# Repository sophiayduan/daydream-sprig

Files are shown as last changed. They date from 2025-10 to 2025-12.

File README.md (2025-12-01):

# Daydream-Sprig

#### The Daydream-Sprig is a version of the [Sprig](https://github.com/hackclub/sprig) using the bare RP2040 chip and in a vertical handheld formfactor.





I'll be setting it up the same as the Sprig. flashing Spade OS (Sprigs custom operating system)

### Features 
- All pre-exsiting sprig stuff (Rp2040, ST7735 1.8" Display, powered via 2xaaa, etc)
- 6x6mm push buttons
- Vertical handheld form factor
- 4 additional GPIOS
- Cool silkscreen art made by Erin + some stolen from the og sprig

(unlike the original sprig, this board doesn't include a speaker due to its cost)

This project was made as a lanyard for [Daydream Ottawa](https://daydream.hackclub.com/ottawa) organizers (to display their names and other cool stuff) but, I didn't end up finishing it in time oops.

## Acknowledgements
*the sprig.*

jlcpcb 

Thanks JLCPCB for sponsoring DD Ottawa and hence this project.

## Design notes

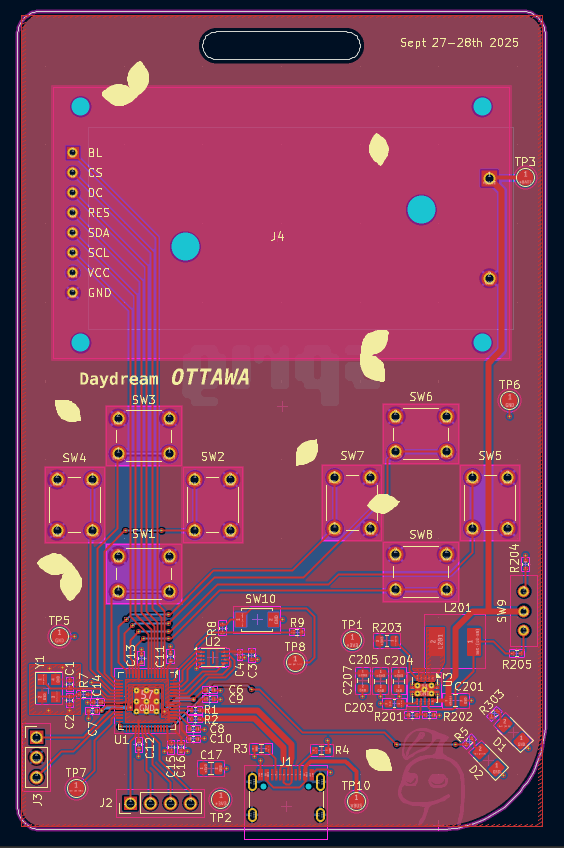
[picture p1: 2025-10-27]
images/pcb_front.png

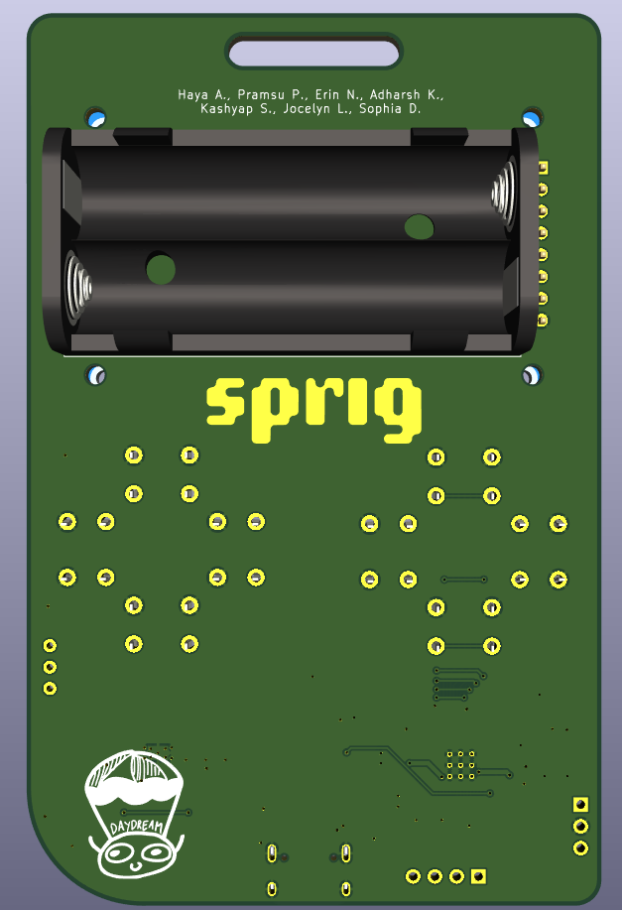
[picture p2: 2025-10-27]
images/3d_back.png

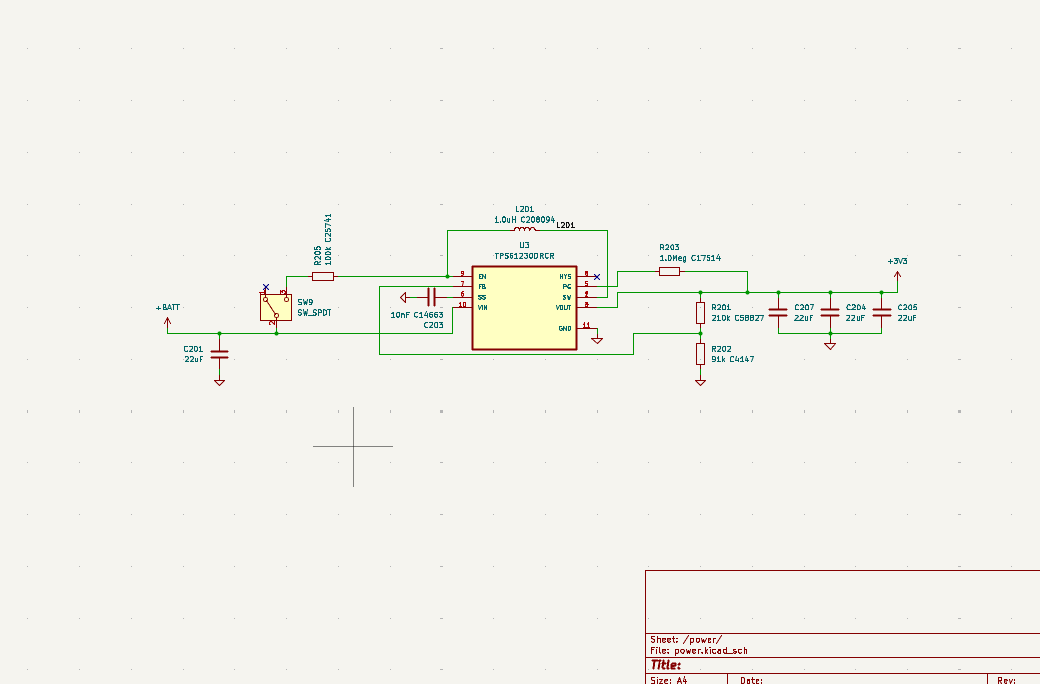
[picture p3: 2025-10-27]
images/sch_power.png

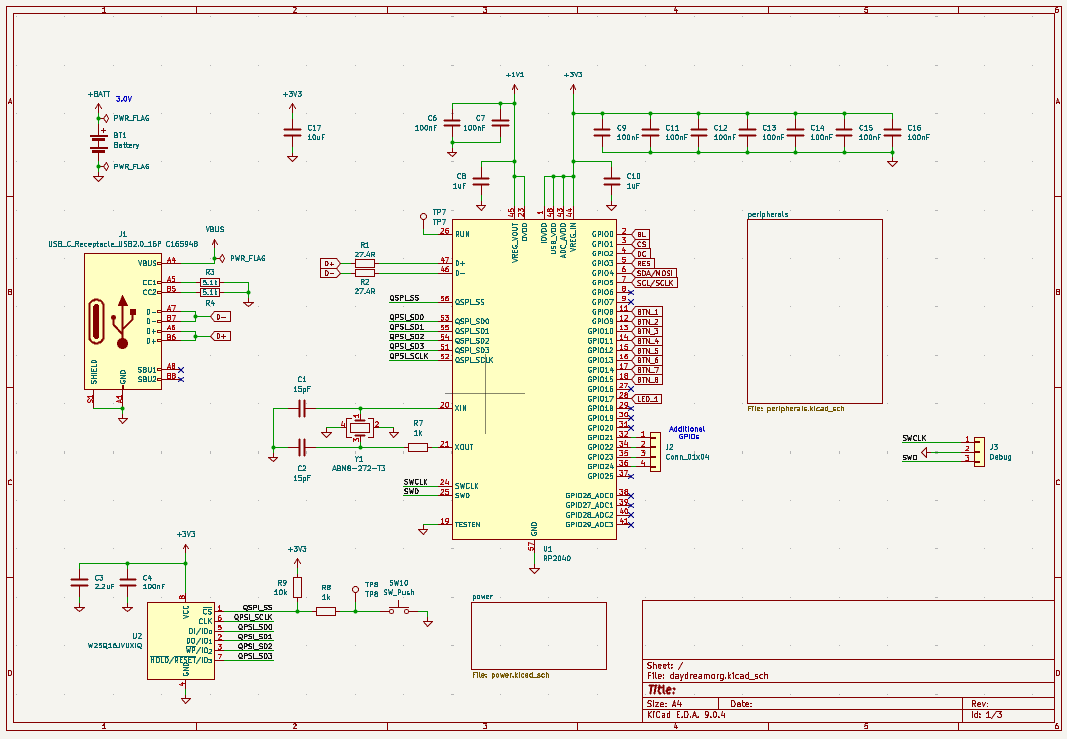
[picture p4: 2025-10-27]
images/sch_main.png

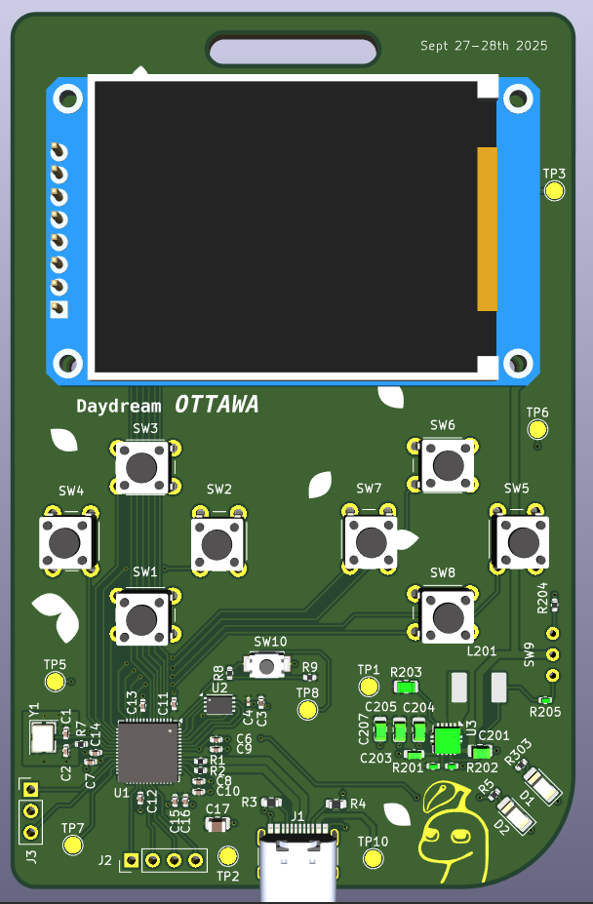
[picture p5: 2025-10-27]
images/3d_front.png

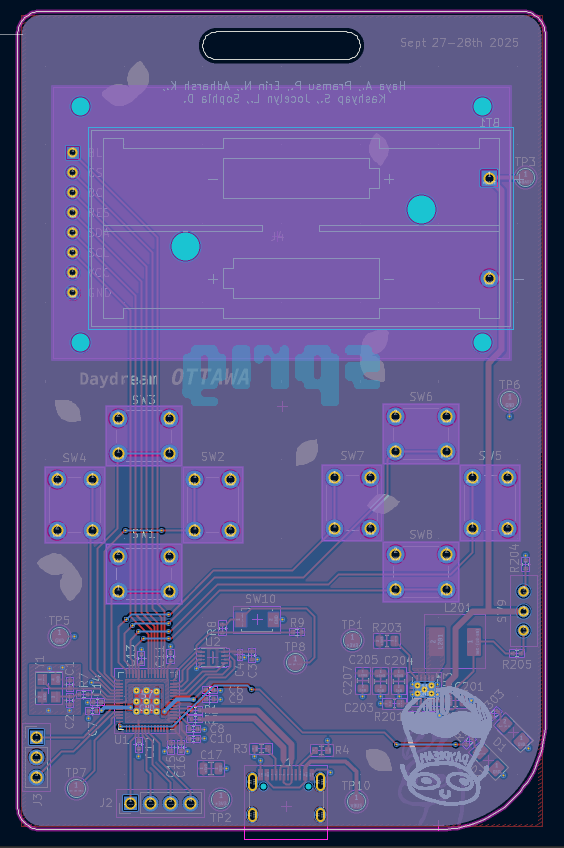
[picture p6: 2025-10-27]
images/pcb_back.png

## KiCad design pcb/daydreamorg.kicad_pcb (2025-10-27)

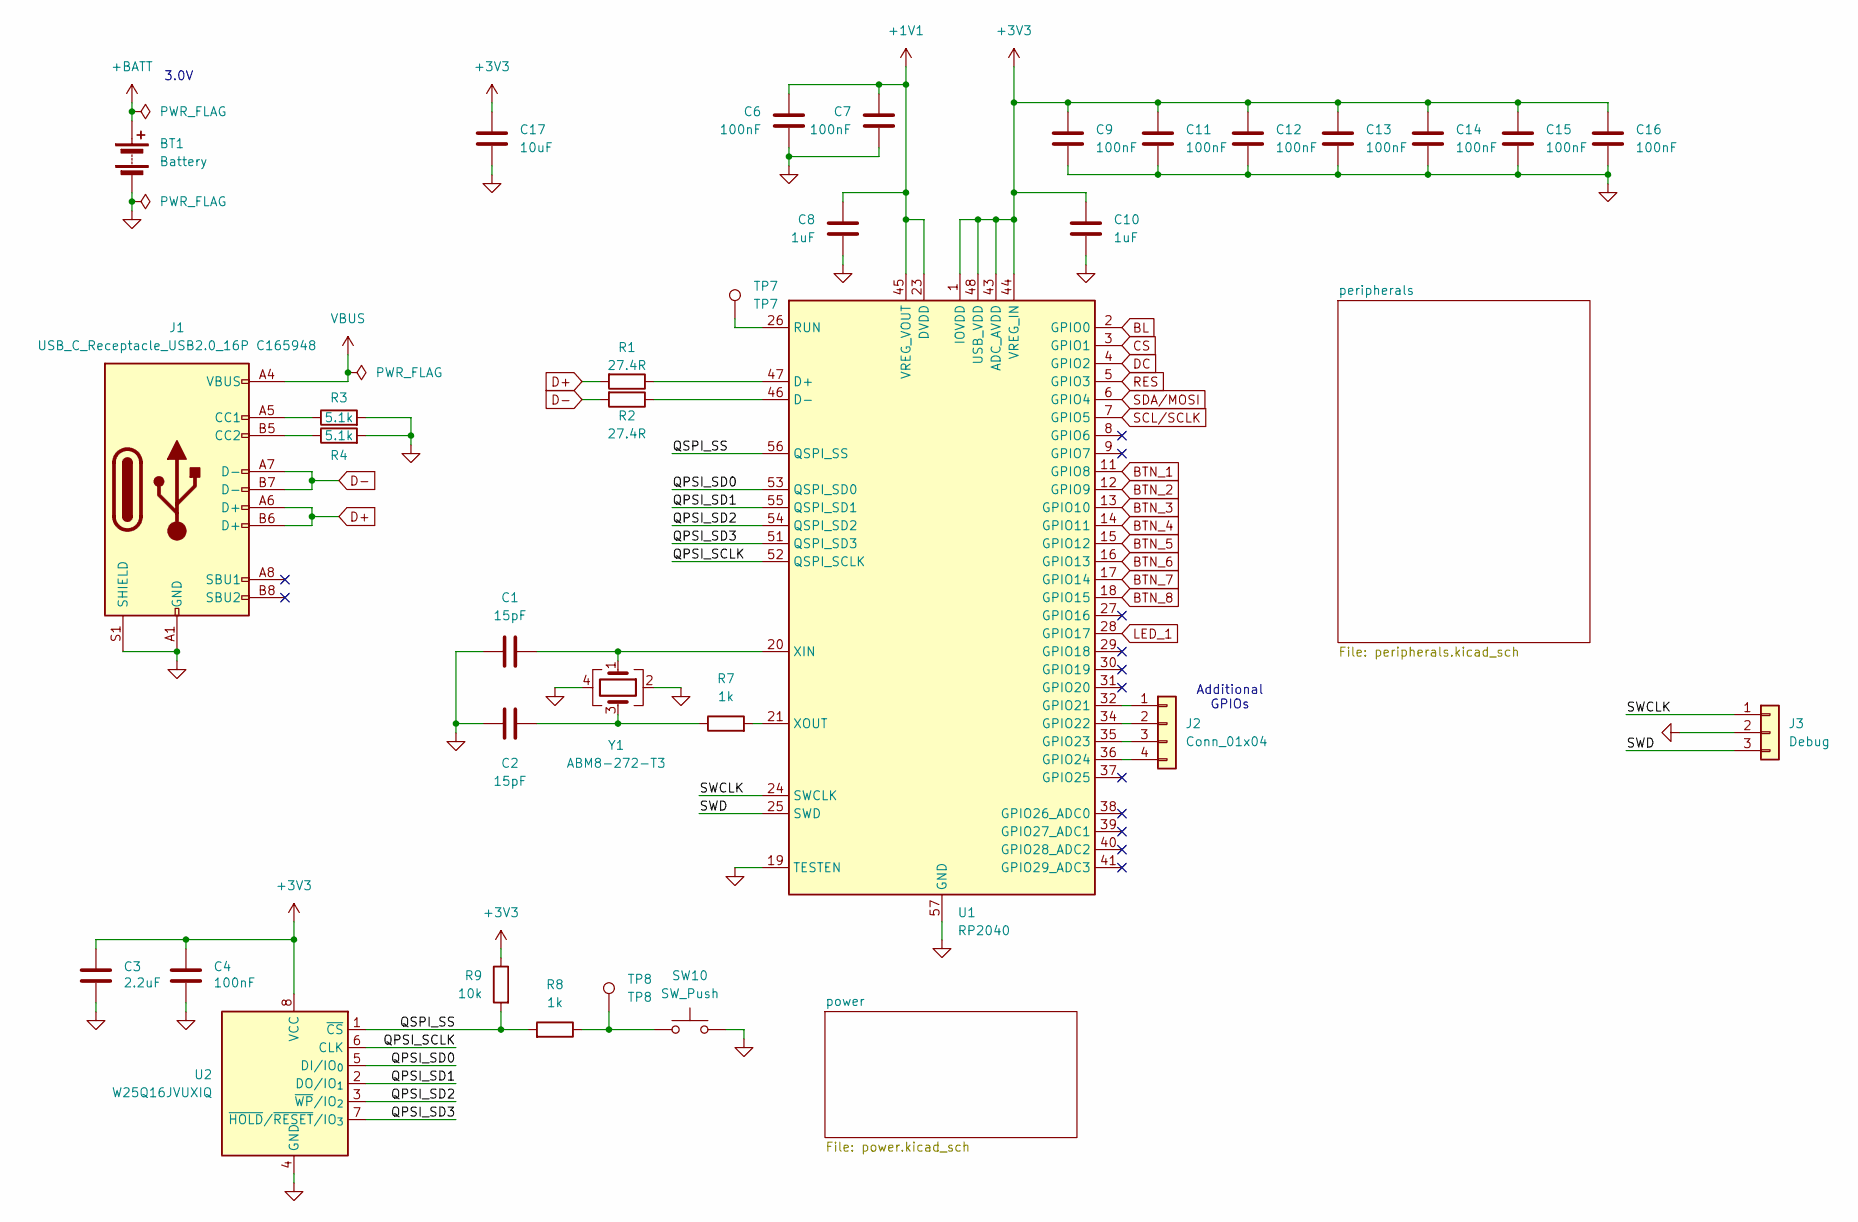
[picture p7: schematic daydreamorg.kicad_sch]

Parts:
BT1: Battery; BatteryHolder_Keystone_2468_2xAAA; LCSC C254917
C1, C2: 15pF; C_0402_1005Metric; LCSC C1548
C3: 2.2uF; C_0402_1005Metric; LCSC C541409
C4: 100nF; C_0603_1608Metric; LCSC C1525
C6, C7, C9, C11, C12, C13, C14, C15, C16: 100nF; C_0402_1005Metric; LCSC C1525
C8, C10: 1uF; C_0402_1005Metric; LCSC C52923
C17: 10uF; C_0805_2012Metric
J1: USB_C_Receptacle_USB2.0_16P C165948; USB_C_Receptacle_HRO_TYPE-C-31-M-12; LCSC C165948
J2: Conn_01x04; PinHeader_1x04_P2.54mm_Vertical
J3: Debug; PinHeader_1x03_P2.54mm_Vertical
R1, R2: 27.4R; R_0402_1005Metric; LCSC C25100
R3, R4: 5.1k; R_0603_1608Metric; LCSC C23186
R7, R8: 1k; R_0402_1005Metric; LCSC C11702
R9: 10k; R_0402_1005Metric
SW10: SW_Push; SW_TS-1088-AR02016; LCSC C720477
TP7: TP7; TestPoint_Pad_D2.0mm
TP8: TP8; TestPoint_Pad_D2.0mm
U1: RP2040; QFN-56-1EP_7x7mm_P0.4mm_EP3.2x3.2mm; LCSC C2040
U2: W25Q16JVUXIQ; SOIC-8_5.3x5.3mm_P1.27mm; LCSC C2843335
Y1: ABM8-272-T3; Crystal_SMD_3225-4Pin_3.2x2.5mm; LCSC C20625731

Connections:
+1V1: C6.1, C7.1, C8.1, U1.23 (DVDD), U1.45 (VREG_VOUT), U1.50 (DVDD)
+3V3: C3.1, C4.1, C9.1, C10.1, C11.1, C12.1, C13.1, C14.1, C15.1, C16.1, C17.1, R9.1, U1.1 (IOVDD), U1.10 (IOVDD), U1.22 (IOVDD), U1.33 (IOVDD), U1.42 (IOVDD), U1.43 (ADC_AVDD), U1.44 (VREG_IN), U1.48 (USB_VDD), U1.49 (IOVDD), U2.8 (VCC); also elsewhere on the board
+BATT: BT1.1 (+); also elsewhere on the board
/QPSI_SCLK: U1.52 (QSPI_SCLK), U2.6 (CLK)
/QPSI_SD0: U1.53 (QSPI_SD0), U2.5 (DI/IO_{0})
/QPSI_SD1: U1.55 (QSPI_SD1), U2.2 (DO/IO_{1})
/QPSI_SD2: U1.54 (QSPI_SD2), U2.3 (~WP/IO_{2})
/QPSI_SD3: U1.51 (QSPI_SD3), U2.7 (~HOLD/~RESET/IO_{3})
/QSPI_SS: R8.2, R9.2, U1.56 (QSPI_SS), U2.1 (~CS)
/SWCLK: J3.1, U1.24 (SWCLK)
/SWD: J3.3, U1.25 (SWD)
BL: U1.2 (GPIO0); also elsewhere on the board
BTN_1: U1.11 (GPIO8); also elsewhere on the board
BTN_2: U1.12 (GPIO9); also elsewhere on the board
BTN_3: U1.13 (GPIO10); also elsewhere on the board
BTN_4: U1.14 (GPIO11); also elsewhere on the board
BTN_5: U1.15 (GPIO12); also elsewhere on the board
BTN_6: U1.16 (GPIO13); also elsewhere on the board
BTN_7: U1.17 (GPIO14); also elsewhere on the board
BTN_8: U1.18 (GPIO15); also elsewhere on the board
CS: U1.3 (GPIO1); also elsewhere on the board
D+: J1.A6 (D+), J1.B6 (D+), R1.2
D-: J1.A7 (D-), J1.B7 (D-), R2.2
DC: U1.4 (GPIO2); also elsewhere on the board
GND: BT1.2 (-), C1.1, C2.1, C3.2, C4.2, C6.2, C7.2, C8.2, C9.2, C10.2, C11.2, C12.2, C13.2, C14.2, C15.2, C16.2, C17.2, J1.A1 (GND), J1.A12 (GND), J1.B1 (GND), J1.B12 (GND), J1.S1 (SHIELD), J3.2, R3.2, R4.2, SW10.2, U1.19 (TESTEN), U1.57 (GND), U2.4 (GND), Y1.2, Y1.4; also elsewhere on the board
LED_1: U1.28 (GPIO17); also elsewhere on the board
unnamed: C2.2, R7.1, Y1.3
unnamed: J1.A5 (CC1), R3.1
unnamed: J1.B5 (CC2), R4.1
unnamed: J2.1, U1.32 (GPIO21)
unnamed: J2.2, U1.34 (GPIO22)
unnamed: J2.3, U1.35 (GPIO23)
unnamed: J2.4, U1.36 (GPIO24)
unnamed: R8.1, SW10.1, TP8.1
unnamed: R1.1, U1.47 (D+)
unnamed: R2.1, U1.46 (D-)
unnamed: TP7.1, U1.26 (RUN)
unnamed: C1.2, U1.20 (XIN), Y1.1
unnamed: R7.2, U1.21 (XOUT)
RES: U1.5 (GPIO3); also elsewhere on the board
SCL/SCLK: U1.7 (GPIO5); also elsewhere on the board
SDA/MOSI: U1.6 (GPIO4); also elsewhere on the board
VBUS: J1.A4 (VBUS), J1.A9 (VBUS), J1.B4 (VBUS), J1.B9 (VBUS); also elsewhere on the board

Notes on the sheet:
Additional GPIOs
3.0V

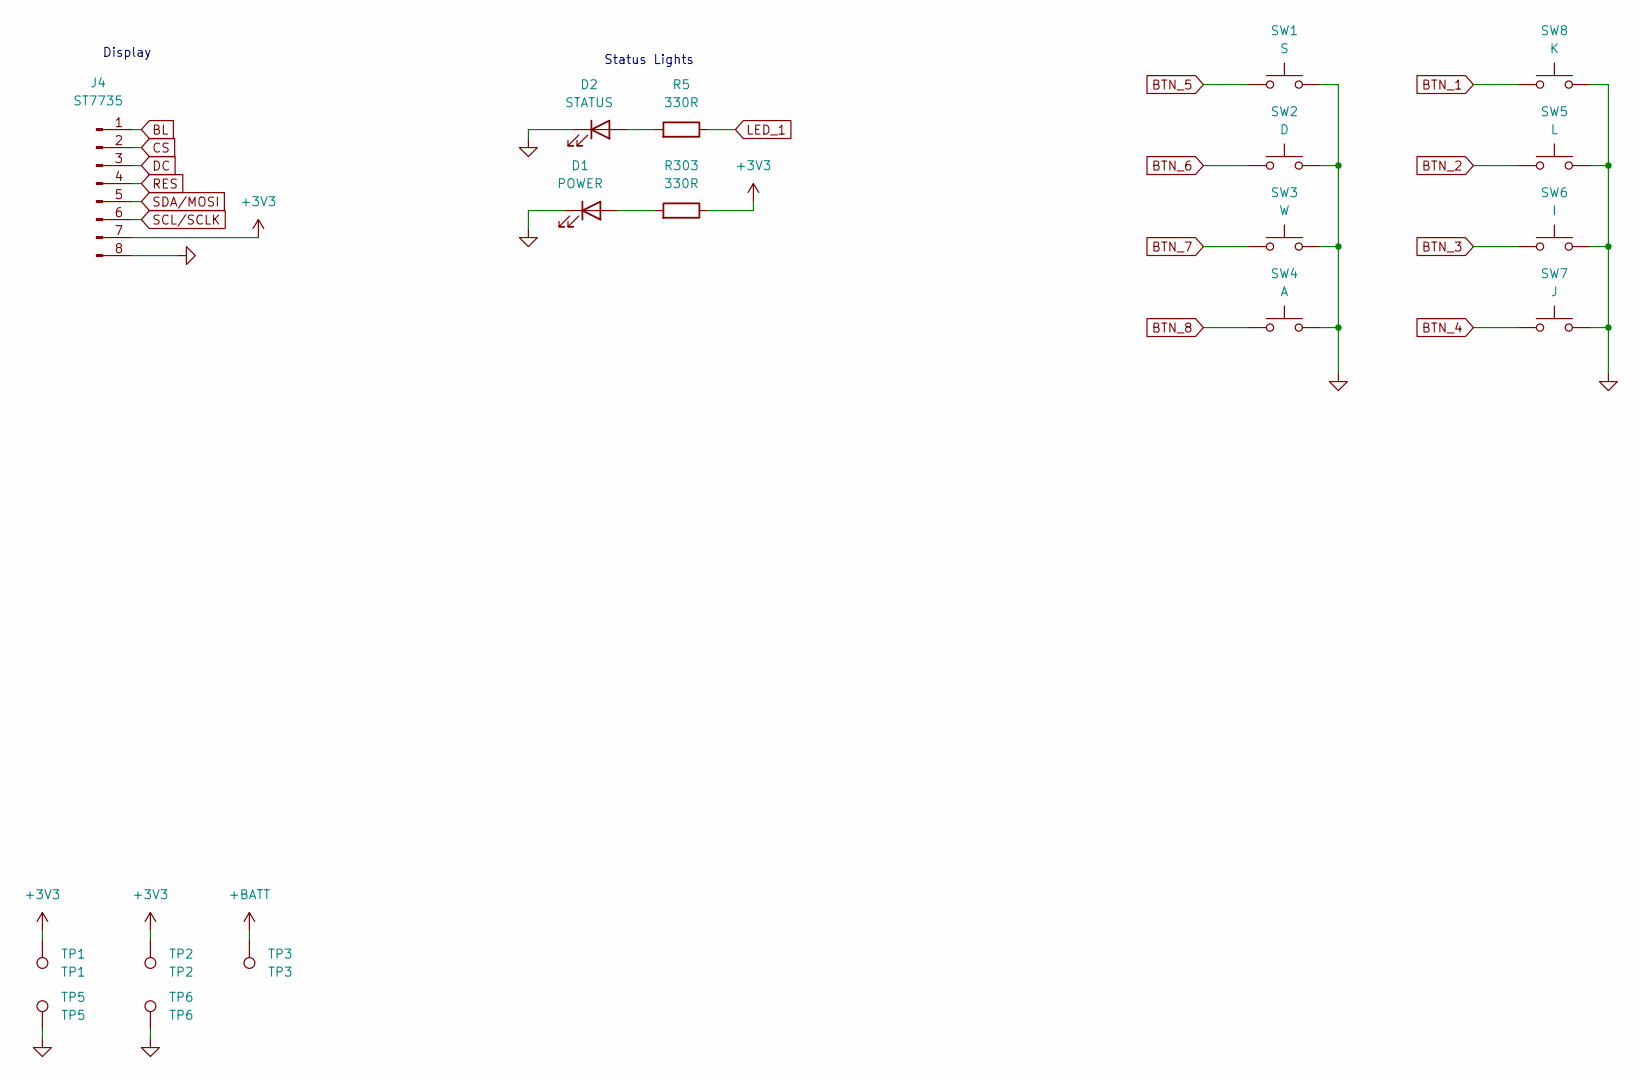
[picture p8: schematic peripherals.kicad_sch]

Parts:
D1: POWER; LED_1206_3216Metric_Pad1.42x1.75mm_HandSolder; LCSC C14641
D2: STATUS; LED_1206_3216Metric_Pad1.42x1.75mm_HandSolder; LCSC C49018
J4: ST7735; st7735
R5, R303: 330R; R_0402_1005Metric; LCSC C25104
SW1: S; SW_PUSH_6mm; LCSC C83205
SW2: D; SW_PUSH_6mm; LCSC C83205
SW3: W; SW_PUSH_6mm; LCSC C83205
SW4: A; SW_PUSH_6mm; LCSC C83205
SW5: L; SW_PUSH_6mm; LCSC C83205
SW6: I; SW_PUSH_6mm; LCSC C83205
SW7: J; SW_PUSH_6mm; LCSC C83205
SW8: K; SW_PUSH_6mm; LCSC C83205
TP1: TP1; TestPoint_Pad_D2.0mm
TP2: TP2; TestPoint_Pad_D2.0mm
TP3: TP3; TestPoint_Pad_D2.0mm
TP5: TP5; TestPoint_Pad_D2.0mm
TP6: TP6; TestPoint_Pad_D2.0mm

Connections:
+3V3: J4.7, R303.1, TP1.1, TP2.1; also elsewhere on the board
+BATT: TP3.1; also elsewhere on the board
BL: J4.1; also elsewhere on the board
BTN_1: SW8.1; also elsewhere on the board
BTN_2: SW5.1; also elsewhere on the board
BTN_3: SW6.1; also elsewhere on the board
BTN_4: SW7.1; also elsewhere on the board
BTN_5: SW1.1; also elsewhere on the board
BTN_6: SW2.1; also elsewhere on the board
BTN_7: SW3.1; also elsewhere on the board
BTN_8: SW4.1; also elsewhere on the board
CS: J4.2; also elsewhere on the board
DC: J4.3; also elsewhere on the board
GND: D1.1 (K), D2.1 (K), J4.8, SW1.2, SW2.2, SW3.2, SW4.2, SW5.2, SW6.2, SW7.2, SW8.2, TP5.1, TP6.1; also elsewhere on the board
LED_1: R5.1; also elsewhere on the board
unnamed: D1.2 (A), R303.2
unnamed: D2.2 (A), R5.2
RES: J4.4; also elsewhere on the board
SCL/SCLK: J4.6; also elsewhere on the board
SDA/MOSI: J4.5; also elsewhere on the board

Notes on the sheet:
Display
Status Lights

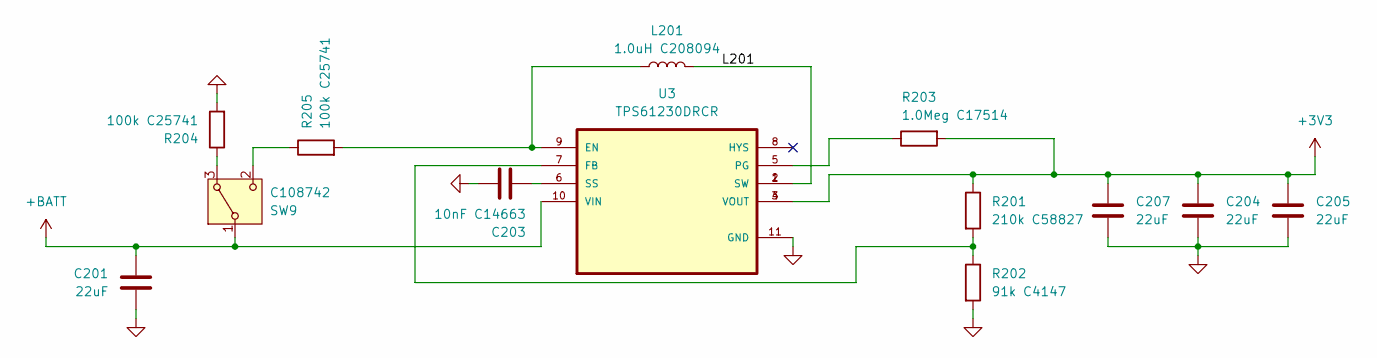
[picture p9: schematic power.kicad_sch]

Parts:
C201: 22uF; C_0805_2012Metric; LCSC C77071
C203: 10nF C14663; C_0603_1608Metric; LCSC C14663
C204, C205, C207: 22uF; C_0805_2012Metric; LCSC C92811
L201: 1.0uH C208094; Untitled_1; LCSC C208094
R201: 210k C58827; R_0402_1005Metric; LCSC C58827
R202: 91k C4147; R_0402_1005Metric; LCSC C4147
R203: 1.0Meg C17514; R_0805_2012Metric; LCSC C17514
R204, R205: 100k C25741; R_0402_1005Metric; LCSC C25741
SW9: C108742; slide switch; LCSC C108742
U3: TPS61230DRCR; TPS123

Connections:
+3V3: C204.1, C205.1, C207.1, R201.1, R203.2, U3.3 (VOUT), U3.4 (VOUT); also elsewhere on the board
+BATT: C201.1, SW9.1 (B), U3.10 (VIN); also elsewhere on the board
/power/L201: L201.2, U3.1 (SW), U3.2 (SW)
GND: C201.2, C203.2, C204.2, C205.2, C207.2, R202.2, R204.2, U3.11 (GND); also elsewhere on the board
unnamed: R204.1, SW9.3 (A)
unnamed: R205.1, SW9.2 (C)
unnamed: L201.1, R205.2, U3.9 (EN)
unnamed: R201.2, R202.1, U3.7 (FB)
unnamed: R203.1, U3.5 (PG)
unnamed: C203.1, U3.6 (SS)

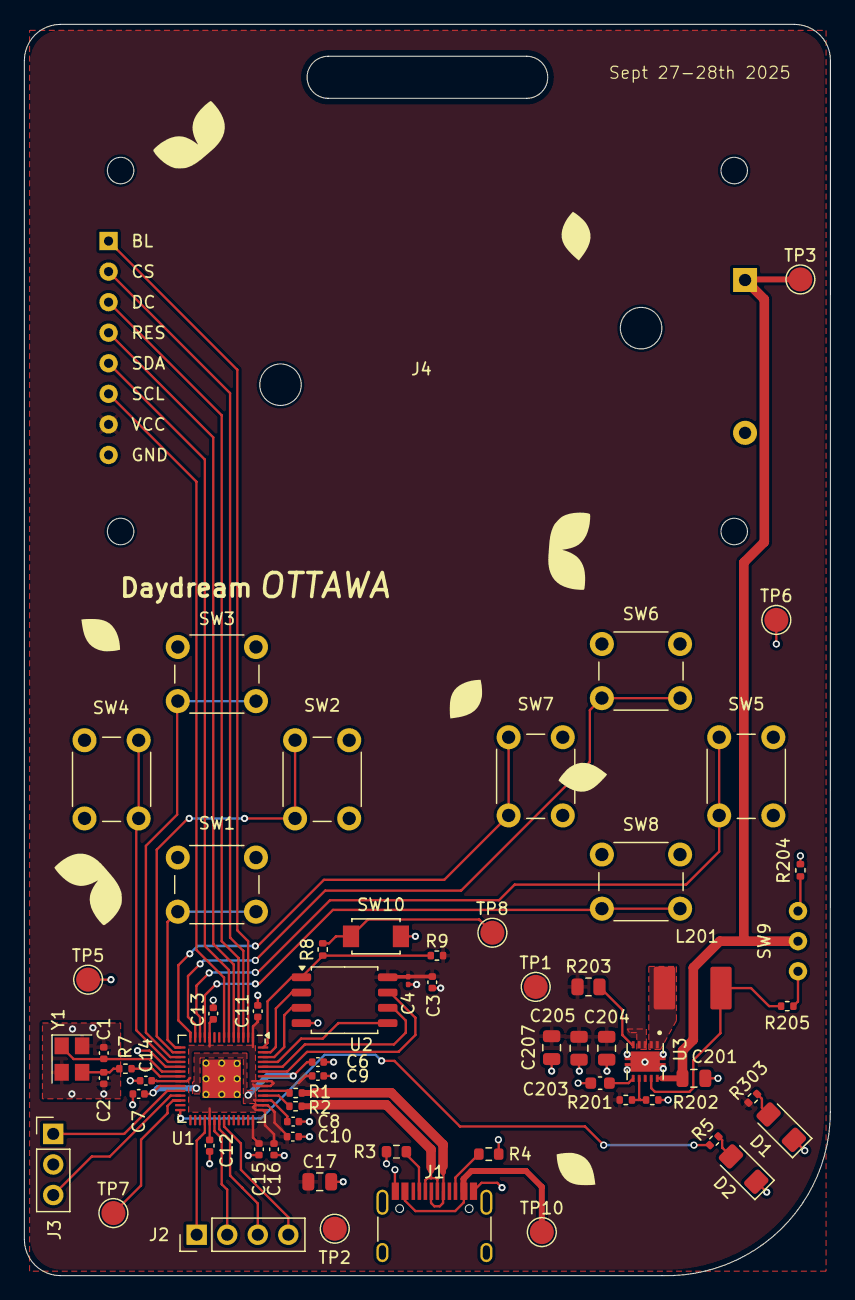
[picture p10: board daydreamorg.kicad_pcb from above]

Board: 2 copper layers, 67.0 x 104.0 mm, 65 parts (1 on the bottom side), 52 nets.

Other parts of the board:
TP10: TestPoint; TestPoint_Pad_D2.0mm

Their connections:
VBUS: TP10.1; also elsewhere on the board

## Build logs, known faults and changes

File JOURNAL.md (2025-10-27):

---
Title: "Daydream Ottawa's organizer pcb"
Author: "Sophia"
Description: "Basically a sprig but with the bare rp2040 and ressembling a gameboy"
Created On: "21/8/2025"
---

~~Total time: 33.5h~~

> edit: upon realizing i have 34h tracked on hackatime, then 33.5h for sure isn't my total time. I'd estimate 40h at the minimum then, but (hi reviewer!) i'd understand if you need to reduce some. 

### Estimated total time: 40h.

# August 22nd: Basic plan

**Time: 1h**

(I'm journalling this retrospectively) I originally intended for this to be a rp2040 devboard, hence I started with that an began looking through some resources 
(mainly the rp2040 [datasheet](https://datasheets.raspberrypi.com/rp2040/rp2040-datasheet.pdf) and [design](https://datasheets.raspberrypi.com/rp2040/hardware-design-with-rp2040.pdf) documents. This was researching session.

# August 31st: Back to work

**Time: 1.5h**

Had some personal stuff but now we're back and better than ever. I finalized my idea to basically be a version of the sprig, as there are already firmare and hundreds of pre-coded games!
The schematic is still quite lacking and there are a lot more specificities I need to figure out so that the sprig games will run on this. Some differences is I will be using 4.5 via 3 x AAA batteries and potentially have a larger display (not sure about this one).

My hierachial pages are still empty and the I haven't quite figured out how I want to flash this.


# September 5th:
**Time: 0.5h**

I ended up switching to using a RT615BGQW (the pi pico uses the 3.3v version) and it'll provide 800mA which should be enough. 

# Sept 6-15th:
#### During the chunk from sept 6-15th I was working whenever I had some spare time and didn't even up documenting it (sorry reviewer!).

(My time was tracked in hackatime **~14h**, not including the many hours looking at datasheets and forgetting to run kicad-wakatime)

Being very conservative (as I didn't journal properly) I'm gonna say time for this period was 16h, I definitely spent more than 2hrs on the datasheets.
**Time: 16h**

#### So here's a summary of all the things I did:
- Realized incorporating audio is too expensive
- After multiple iterations I settled on having 2xaaa batteries (3.0V) as the power source then having it converted to 3.3V via the TPS61230DRCR:


^^ its really messy and will be cleaned up in the future

- Switched from the TK to W25Q16JVUXIQ as I realized I didn't need much storage (I copied this part from the pi pico): 


- Added all my peripherals:


- Created a basic layout, very rough but it existed 

# September 16th:

**Time: 5.5h**

Lots of progress made:
- aligned buttons
- finalized the edge cut
- added silkscreen art/text
- followed the rp2040 hardware design guide for the pours under the mcu
- added additional gpio pin headers


(i realize the angle is weird)

# September 17th:

**Time: 3h**

- made a footprint for the inductor
- made footprint for the ST7735 (with help from the sprig) and realized my schematic was completely wrong (it was for the microsd card version of this display)
- finalized the placements
- temporarily removed the test points
- added silk screen art
- realized I don't need mounting holes (I may go back on this)
- found footprints for all the remaining power section components and routed all of those
- found all lcsc parts

I finally finished this. Well mostly. 

Before I finalize this i'll change the font, finalize the silkscreen art, clean up the schematic, make silkscreen text consistent and clear, check all my datasheets, add in test points, verify all my lcsc parts and hope.




# September 18th:

**Time: 3h**
Today I worked a bit more on the things I mentioned yesterday.
Then I started going through to review every datasheet and each components LCSC part, this was very time consuming. 

That's when I saw that the TPS123DRCR provides a layout guide, something I completly missed in the too much time I spent looking at that datasheet. 

So I redid the entire power section, then continued on to move the leds, add sprig logos + silkscreen.  


# September 19th:

**Time: 3h**

Holy freak thank goodness I'm being super meticulous going through every little thing (hopefully nothing falls through the cracks) but I noticed I was using the wrong footprint for the TPS123DRCR, I was using the footprint of a step up converter I was planning on using earlier on.

# Oct 27th:

I'm gonna call this project done now, as the design and everything is finished. I've still gotta convert this to easyeda to get the costs covered but it'll do that in my own time.

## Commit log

2025-10-27 move pcb files into folder
    [daydreamorg.kicad_pcb, daydreamorg.kicad_sch, peripherals.kicad_sch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]
2025-10-27 add pcb images
